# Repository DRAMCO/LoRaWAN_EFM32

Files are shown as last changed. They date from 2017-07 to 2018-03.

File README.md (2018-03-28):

# LoRaWAN_EFM32



LoRaMAC implementation based on the Semtech implemenation for the EFM32 Happy Gecko develop board.
Developed by [DRAMCO](http://www.dramco.be).

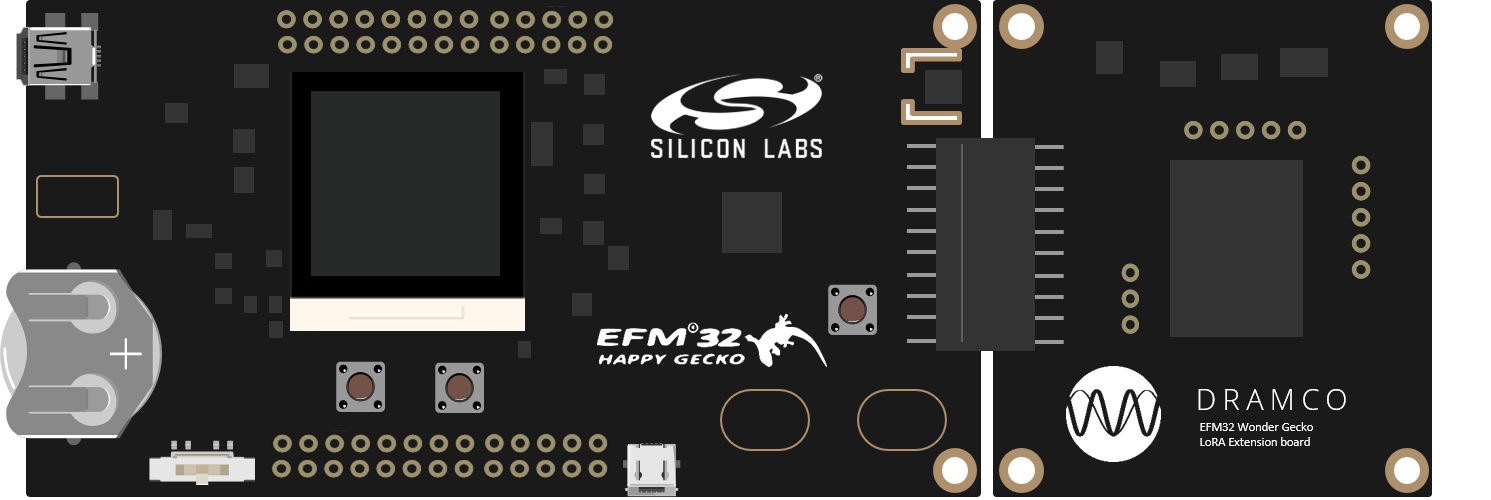
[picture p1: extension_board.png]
LoRaWAN EFM32 module


This project will be used in hands-on sessions to let attendees experience the development of low power IoT nodes.
The module was used in the following tutorials:
- [IEEE Sensors 2017](http://ieee-sensors2017.org/low-power-wireless-technologies-connecting-embedded-sensors-iot-journey-fundaments-hands)
- [IEEE PIMRC 2017](http://pimrc2017.ieee-pimrc.org/program/tutorials-2/)
- Workshop: [Connecting Embedded Sensors in the IoT](https://dramco.be/tutorials/connecting-embedded-sensors-in-the-iot)

The hands-on can be found [here](dramco.be/tutorials/low-power-iot) with the corresponding [presentation](https://www.slideshare.net/GillesCallebaut/low-power-wireless-technologies-for-connecting-embedded-sensors-in-the-iot-a-journey-from-fundaments-to-handson-90398582).

The DRAMCO LoRa module features a Semtech SX1272 Radio chip and an EFM32 Cortex M0 processor. 

## How to cite
```LaTex
@Misc{lorawan-efm32,
  author =   {G. Ottoy and G. Leenders and G. Callebaut},
  title =    {{LoRaWAN EFM32}},
  url = {https://github.com/DRAMCO/LoRaWAN_EFM32},
  note = {doi: \url{10.5281/zenodo.1209414}}
}
```

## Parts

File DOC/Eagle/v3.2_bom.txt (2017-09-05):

Partlist

Exported from v3.brd at 23/08/2017 9:41

EAGLE Version 8.2.2 Copyright (c) 1988-2017 Autodesk, Inc.

Assembly variant: 

Part     Value                 Package                  Library  Supplier   Ordernr          Price/piece

C1       10n                   C0805K                   rcl      
C2       100n                  C0805K                   rcl      
C3       100n                  C0805K                   rcl      
C4       100n                  C0805K                   rcl      
C5       1u                    C0805K                   rcl      
IC1      APDS-9200             APDS-9200                project  Mouser     630-APDS-9200    1.37
IC2      PIC12LF1552           MSOP8                    project  RS         799-0281	     0.559 (per 10)
IC3      M24C01/02-XTSSOP08    TSSOP08                  project  RS         714-7575	     0.141 (per 25)
JP1      SMH-110-X2-XX-D       SMH-110-X2-XX-D          project  Farnell    2019809          4.03
JP2                            1X03                     pinhead
JP3                            1X06                     pinhead
JP4                            1X04                     pinhead  
JP5                            1X05                     pinhead  
JP6      PICKIT-HEADERSMD-PADS 1X06/SMD                 project  
LED1                           CHIP-LED0805             led      RS         654-5773	     0.052 (per 50)
M1       RF-LORA-868-SO        RF-LORA-868-SO           project  RS         903-3059	    13.50
R1       4k7                   M0805                    rcl      
R2       4k7                   M0805                    rcl      
R3       4k7                   M0805                    rcl      
R4       1k2                   M0805                    rcl      
R5       6k8                   M0805                    rcl      
X1       SMA-142-0701-871/876  J502-ND-142-0701-871/876 con-coax Farnell    2340523          4.77  (min. 10)
A1	 Antenna 868 MHz       /                        /        RS         542-563          5.19

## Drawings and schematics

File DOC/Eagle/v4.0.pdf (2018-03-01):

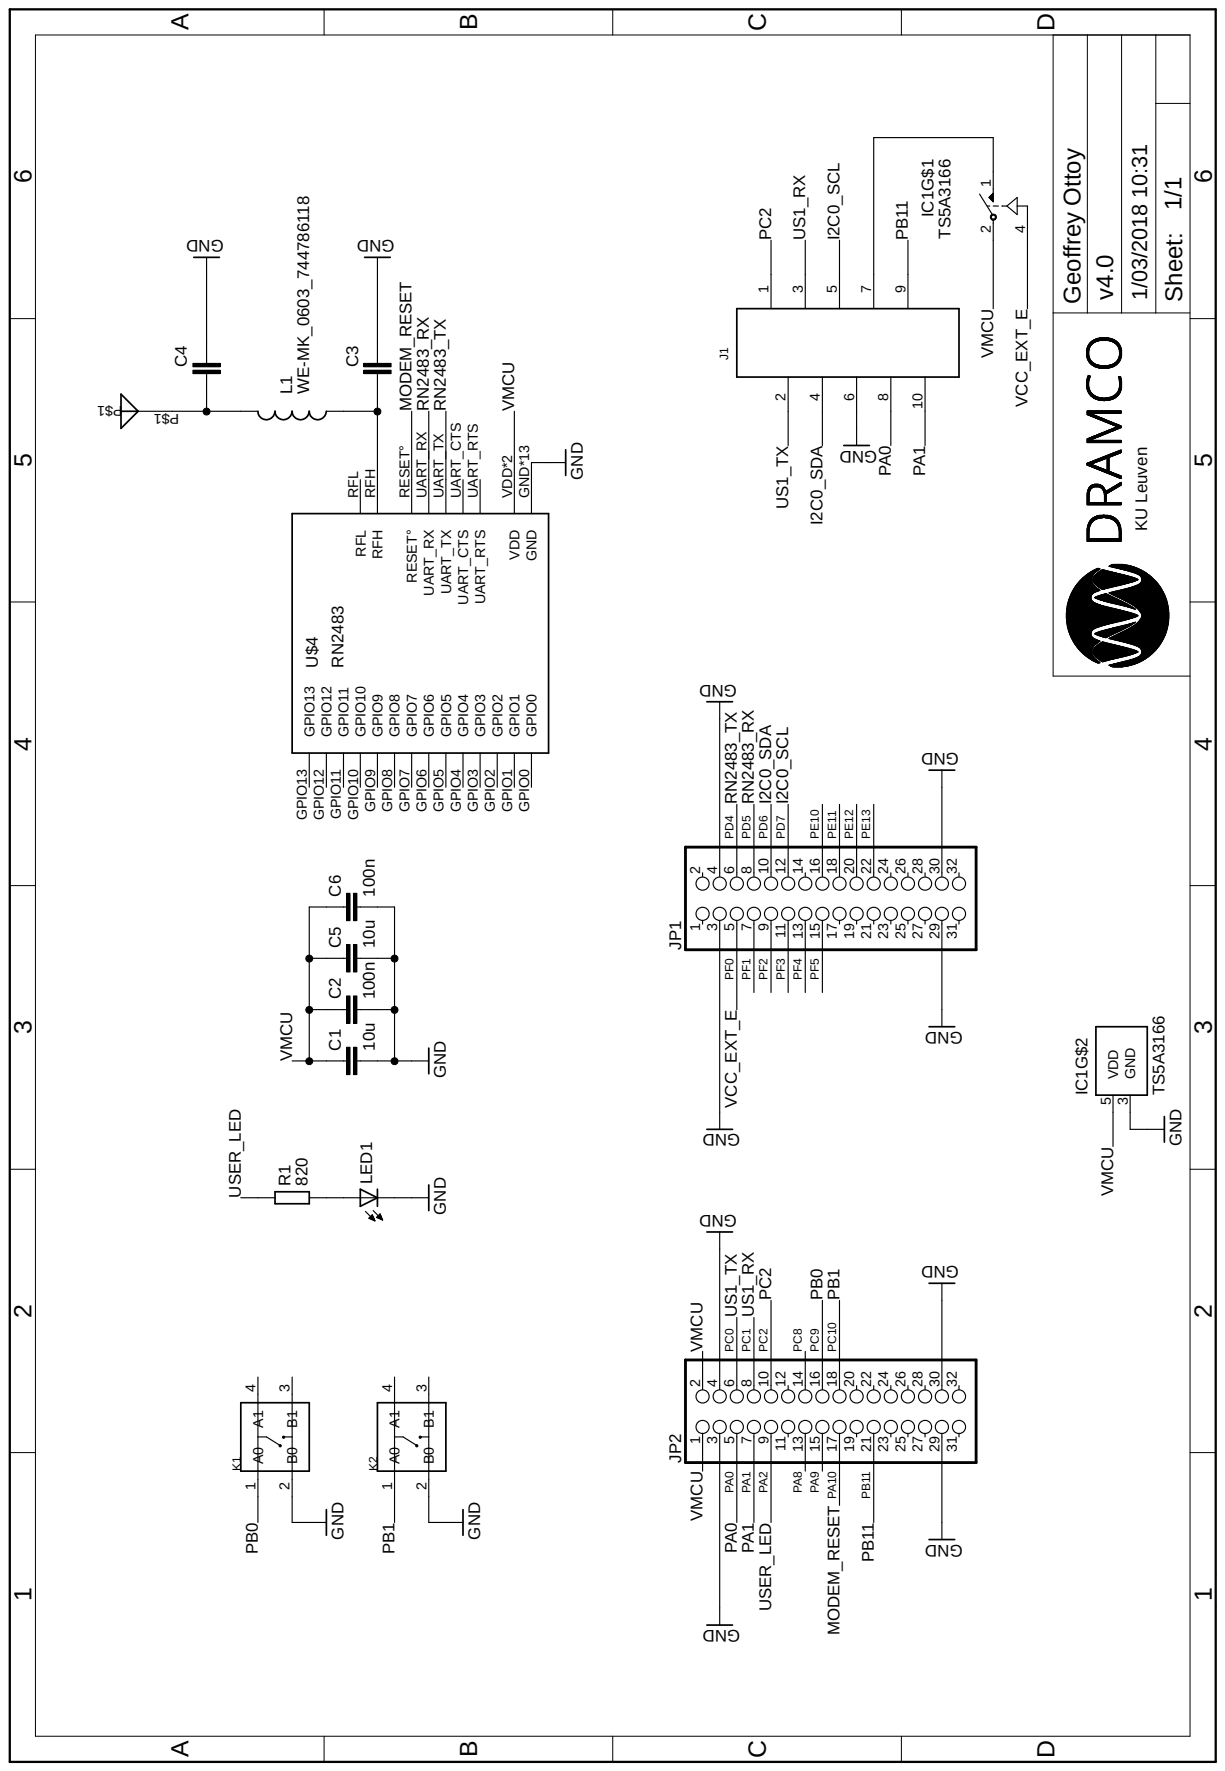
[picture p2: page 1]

P$1 P$1 L1 C5 C6 IC1G$1 4 1 2 IC1G$2 GND 3 VDD 5 VMCU VMCU VMCU VMCU VMCU VMCU PC0 PC1 PC2 PC2 PC8 PC9 PC10 PA0 PA0 PA1 PA1 PA2 PA8 PA9 PA10 PB11 PB11 PD4 PD5 PD6 PD7 PE10 PE11 PE12 PE13 PF0 PF1 PF2 PF3 PF4 PF5 v4.0 1/03/2018 10:31 1/1 Sheet: ABCD 1 2 3 4 5 6 ABCD 1 2 3 4 5 6

Geoffrey Ottoy KU Leuven 10u 100n GND RN2483 GND

GND GND WE-MK_0603_744786118 10u 100n TS5A3166 TS5A3166 GND I2C0_SDA I2C0_SCL PC2 PB0 PB1 PA0 PA1 PB11 MODEM_RESET RN2483_RX RN2483_TX RN2483_TX RN2483_RX MODEM_RESET I2C0_SCL I2C0_SDA US1_TX US1_RX US1_TX US1_RX PB0 PB1 USER_LED USER_LED VCC_EXT_E VCC_EXT_E C1 C2 GND GND*13 UART_TX UART_TX UART_RX UART_RX VDD VDD*2 RFH RFH RFL RFL RESET° RESET° U$4 UART_CTS UART_CTS UART_RTS UART_RTS GPIO0 GPIO0 GPIO1 GPIO1 GPIO2 GPIO2 GPIO3 GPIO3 GPIO4 GPIO4 GPIO5 GPIO5 GPIO6 GPIO6 GPIO7 GPIO7 GPIO8 GPIO8 GPIO9 GPIO9 GPIO10 GPIO10 GPIO11 GPIO11 GPIO12 GPIO12 GPIO13 GPIO13 JP21 2 3 4 5 6 7 8 9 10 11 12 13 14 15 16 17 18 19 20 21 22 23 24 25 26 27 28 29 30 31 32 JP11 2 3 4 5 6 7 8 9 10 11 12 13 14 15 16 17 18 19 20 21 22 23 24 25 26 27 28 29 30 31 32 J1 10 9 8 7 6 5 4 3 2 1 K1A0 1 A1 4 B0 2 B1 3 K2A0 1 A1 4 B0 2 B1 3 R1LED1 C4 C3

GND GND GND 820 GND

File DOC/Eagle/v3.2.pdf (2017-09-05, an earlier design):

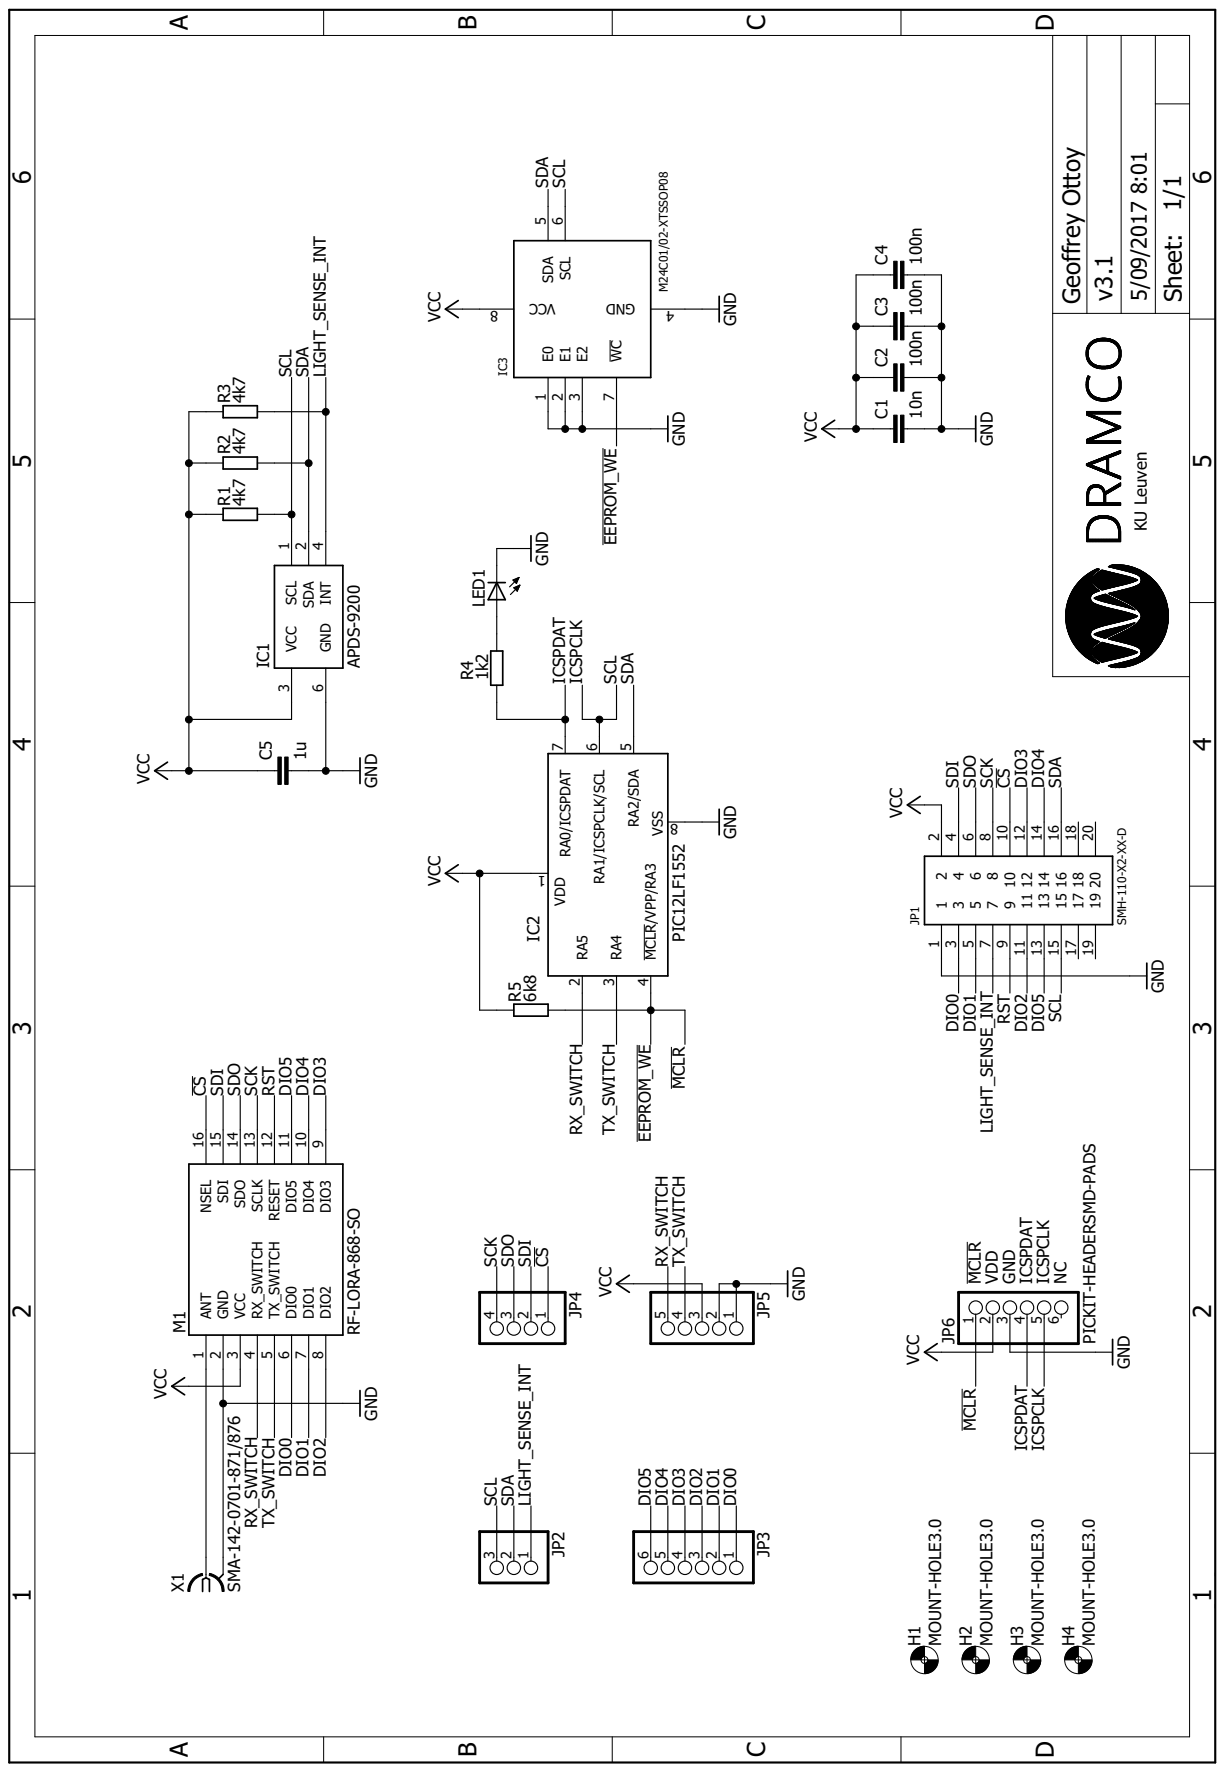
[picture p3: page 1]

Geof rey Ottoy KU Leuven MCLR VDD GND ICSPDAT ICSPCLK NC SMH-110-X2-XX-D GND VCC RF-LORA-868-SO VCC SMA-142-0701-871/876GND 10n 100n VCC GND 4k7 4k7 4k7 1u GND VCC VCC GND APDS-9200 MOUNT-HOLE3.0 MOUNT-HOLE3.0 MOUNT-HOLE3.0 MOUNT-HOLE3.0 PICKIT-HEADERSMD-PADS PIC12LF1552 GND 100n VCC GND VCC 100n M24C01/02-XTSSOP08 VCC GND GND 1k2 GND 6k8 ICSPCLK ICSPCLK EEPROM_WE EEPROM_WE JP11 1 2 2 3 3 4 4 5 5 6 6 7 7 8 8 9 9 10 10 11 11 12 12 13 13 14 14 15 15 16 16 17 17 18 18 19 19 20 20 ANT 1 GND 2 VCC 3 RX_SWITCH 4 TX_SWITCH 5 DIO0 6 DIO1 7 DIO2 8 DIO3 9 DIO4 10 DIO5 11 RESET 12 SCLK 13 SDO 14 SDI 15 NSEL 16 M1 X1 C1 C2 R1 R2 R3 C5 JP2 321JP3 654321 JP4 4321JP5 54321 VCC 3 GND 6 SCL 1 SDA 2 INT 4 IC1 H1H2H4H3 JP6123456 VDD VSS IC2 1 8 RA5 2 RA0/ICSPDAT 7 RA4 3 RA2/SDA 5 RA1/ICSPCLK/SCL 6 MCLR/VPP/RA3 4 C3 C4 E0 1 E1 2 E2 3 DNG 4 SDA 5 SCL 6 WC 7 CCV 8IC3 LED1 R4 R5 RX_SWITCH RX_SWITCH RX_SWITCH TX_SWITCH TX_SWITCH TX_SWITCH DIO0 DIO0 DIOD0IO1 DIO1 DIO1 DIO2 DIO2 DIO2 SCK SCK SCK SDO SDO SDO SDI SDI SDI CS CS CS RST RST DIO5 DIO5 DIO5 DIO4 DIO4 DIO4 DIO3 DIO3 DIO3 SCL SCL SCL SCL SCL SDA SDA SDA SDA SDA LIGHT_SENSE_INT LIGHT_SENSE_INT LIGHT_SENSE_INT ICSPDAT ICSPDAT MCLR MCLR v3.1 5/09/2017 8:01 1/1 Sheet: ABCD 1 2 3 4 5 6 ABCD 1 2 3 4 5 6

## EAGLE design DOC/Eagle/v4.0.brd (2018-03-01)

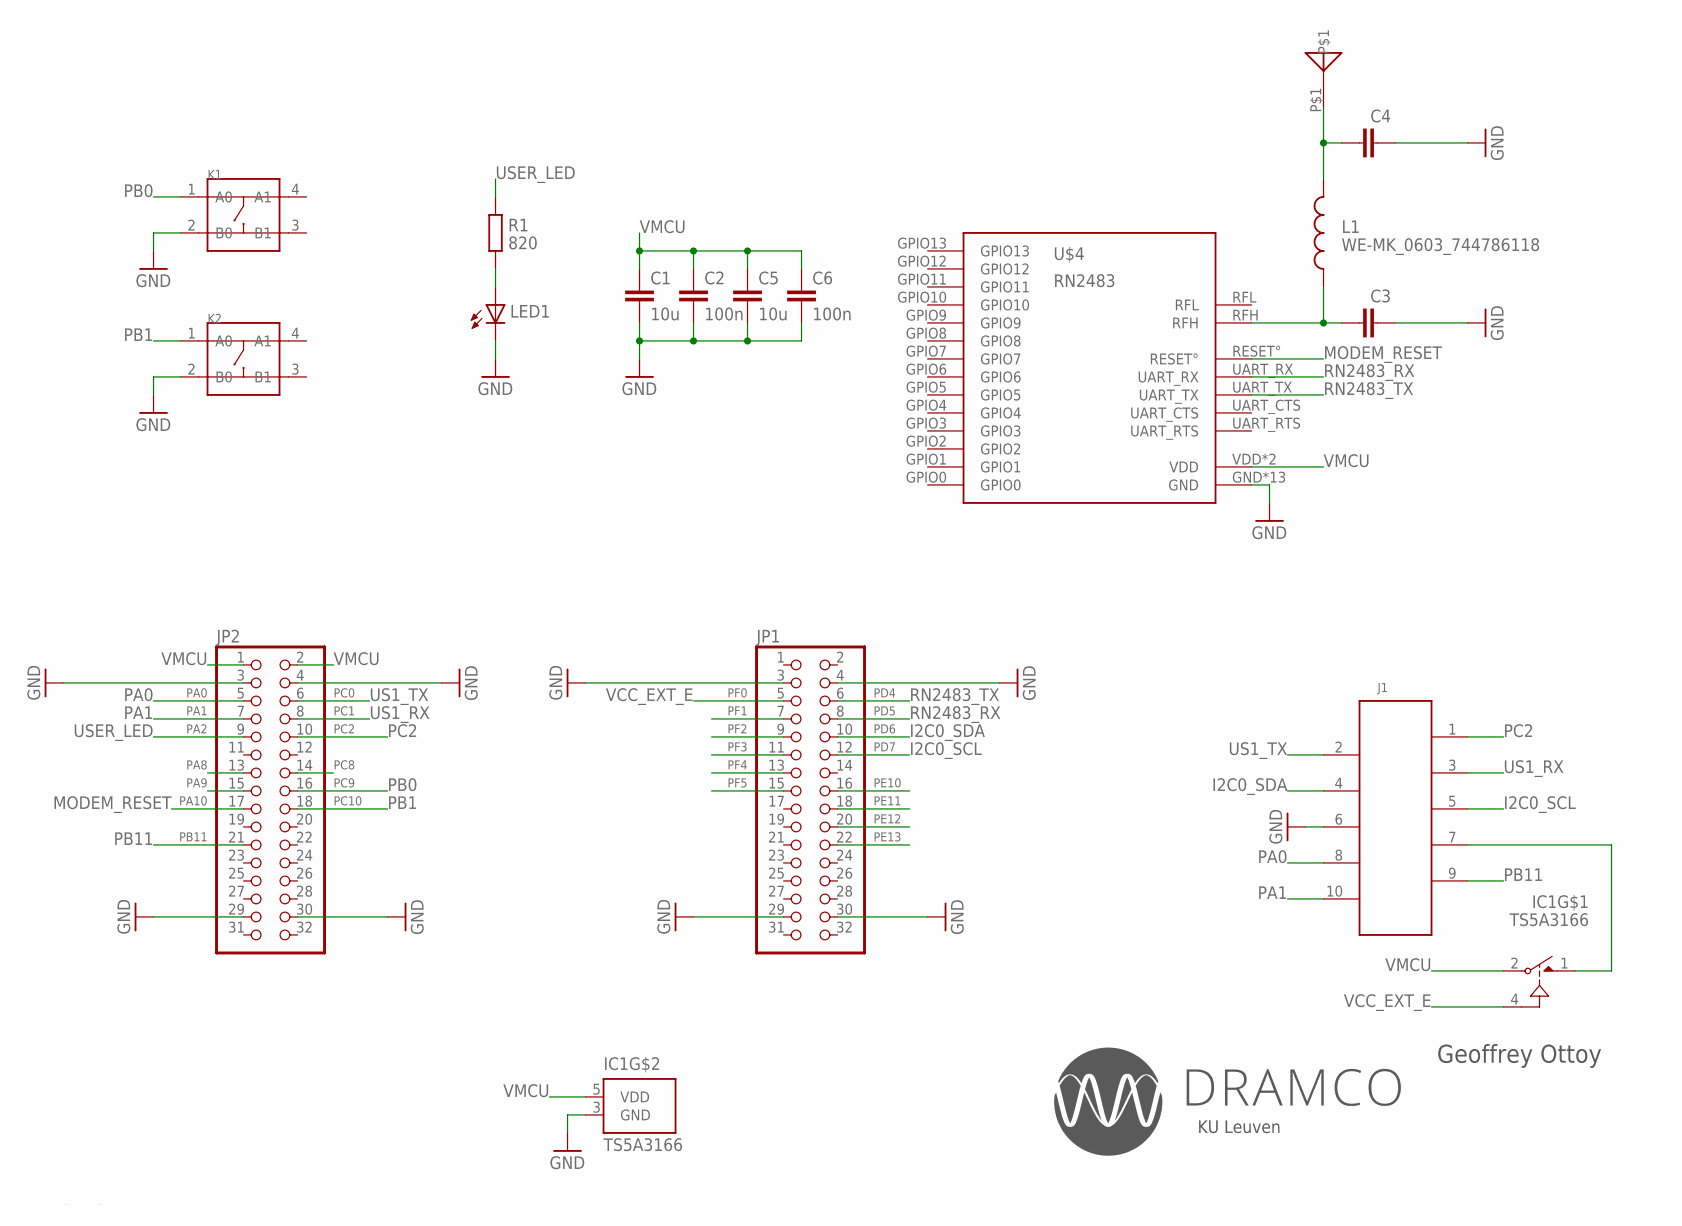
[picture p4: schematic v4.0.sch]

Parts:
C1, C5: 10u; C0805K
C2, C6: 100n; C0805K
C3, C4: C-EUC0603K; C0603K
IC1: TS5A3166; SC70-5L
J1: 61001018321
JP1, JP2: PINHD-2X16; 2X16
K1, K2: SMD-SWITCH-TACTILE-SPST-NO(4P-D6.0MM); SW4-SMD-6.0X6.0X5.0MM
L1: WE-MK_0603_744786118; WE-MK_0603
LED1: LEDCHIPLED_0805; CHIPLED_0805
R1: 820; R0805
U$2: ANTENNA868; CERAMIC-ANTENNA
U$4: RN2483

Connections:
GND: C1.2, C2.2, C3.1, C4.1, C5.2, C6.2, IC1.3 (GND), J1.6 (5), JP1.3, JP1.4, JP1.29, JP1.30, JP2.3, JP2.4, JP2.29, JP2.30, K1.2 (B0), K2.2 (B0), LED1.C, U$4.GND, U$4.GND1 (GND), U$4.GND2 (GND), U$4.GND3 (GND), U$4.GND4 (GND), U$4.GND5 (GND), U$4.GND6 (GND), U$4.GND7 (GND), U$4.GND8 (GND), U$4.GND9 (GND), U$4.GND10 (GND), U$4.GND11 (GND), U$4.GND12 (GND)
unnamed: LED1.A, R1.1
unnamed: C3.2, L1.1, U$4.RFH
unnamed: C4.2, L1.2, U$2.P$1
unnamed: IC1.1 (NO), J1.7 (4)
PA0: J1.8 (3), JP2.5
PA1: J1.10 (1), JP2.7
PA2: JP2.9, R1.2
PA8: JP2.13
PA9: JP2.15
PA10: JP2.17, U$4.RESET°
PB11: J1.9 (2), JP2.21
PC0: J1.2 (9), JP2.6
PC1: J1.3 (8), JP2.8
PC2: J1.1 (10), JP2.10
PC8: JP2.14
PC9: JP2.16, K1.1 (A0)
PC10: JP2.18, K2.1 (A0)
PD4: JP1.6, U$4.UART_TX
PD5: JP1.8, U$4.UART_RX
PD6: J1.4 (7), JP1.10
PD7: J1.5 (6), JP1.12
PE10: JP1.16
PE11: JP1.18
PE12: JP1.20
PE13: JP1.22
PF0: IC1.4 (IN), JP1.5
PF1: JP1.7
PF2: JP1.9
PF3: JP1.11
PF4: JP1.13
PF5: JP1.15
VMCU: C1.1, C2.1, C5.1, C6.1, IC1.2 (COM), IC1.5 (VDD), JP2.1, JP2.2, U$4.VDD, U$4.VDD2 (VDD)

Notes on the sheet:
Geoffrey Ottoy
KU Leuven
I2C0_SDA
I2C0_SCL
PC2
PB0
PB1
PA0
PA1
PB11
MODEM_RESET
RN2483_RX
RN2483_TX
US1_TX
US1_RX
USER_LED
VCC_EXT_E

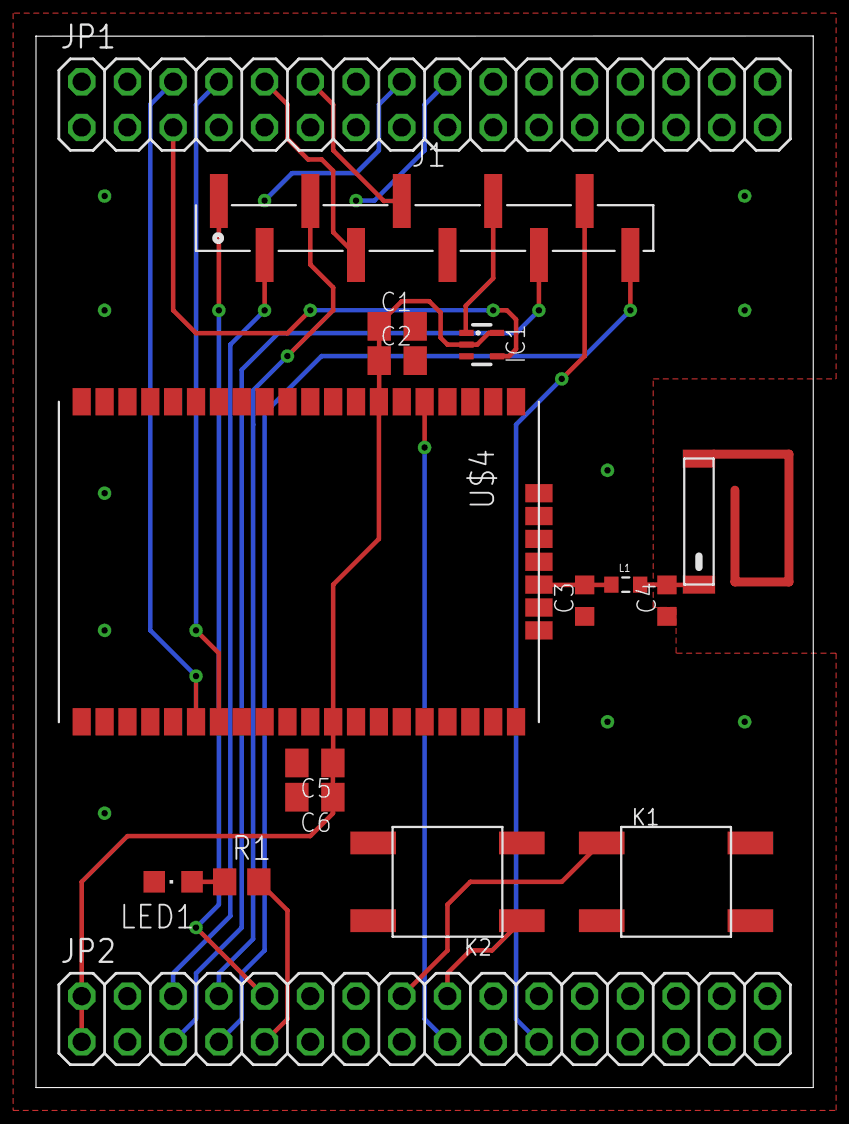
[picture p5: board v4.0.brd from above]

Board: 2 copper layers, 43.2 x 58.4 mm, 17 parts (0 on the bottom side), 21 nets.

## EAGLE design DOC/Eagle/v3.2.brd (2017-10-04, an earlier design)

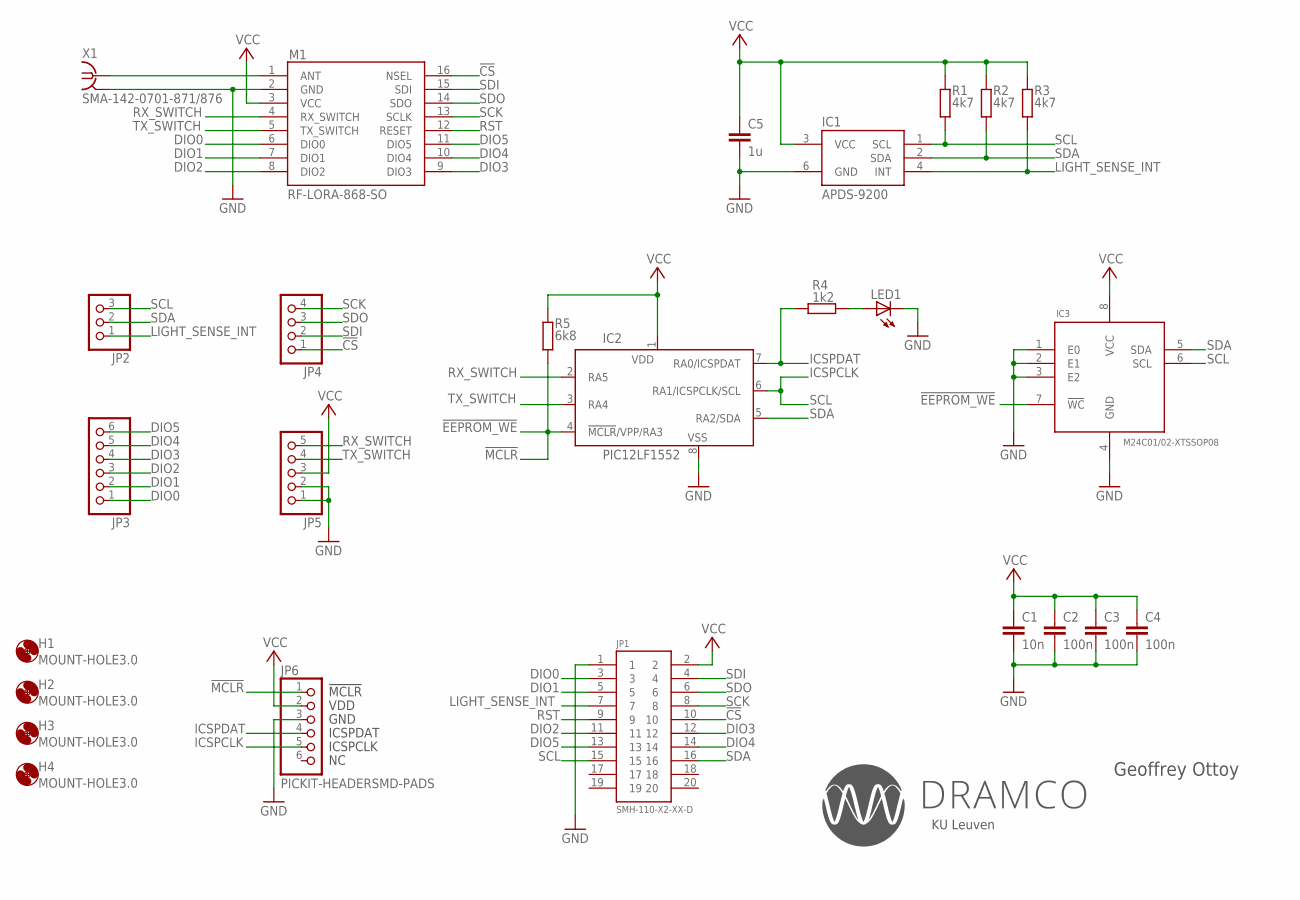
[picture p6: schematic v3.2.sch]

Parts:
C1: 10n; C0805K
C2, C3, C4: 100n; C0805K
C5: 1u; C0805K
H1, H2, H3, H4: MOUNT-HOLE3.0; 3,0
IC1: APDS-9200
IC2: PIC12LF1552; MSOP8
IC3: M24C01/02-XTSSOP08; TSSOP08
JP1: SMH-110-X2-XX-D
JP2: PINHD-1X3; 1X03
JP3: PINHD-1X6; 1X06
JP4: PINHD-1X4; 1X04
JP5: PINHD-1X5; 1X05
JP6: PICKIT-HEADERSMD-PADS; 1X06/SMD
LED1: LEDCHIP-LED0805; CHIP-LED0805
M1: RF-LORA-868-SO
R1, R2, R3: 4k7; M0805
R4: 1k2; M0805
R5: 6k8; M0805
X1: SMA-142-0701-871/876; J502-ND-142-0701-871/876

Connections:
!CS: JP1.10, JP4.1, M1.16 (NSEL)
!MCLR: IC2.4 (!MCLR!/VPP/RA3), IC3.7 (!WC), JP6.1, R5.1
ANT: M1.1 (ANT), X1.1
DIO0: JP1.3, JP3.1, M1.6 (DIO0)
DIO1: JP1.5, JP3.2, M1.7 (DIO1)
DIO2: JP1.11, JP3.3, M1.8 (DIO2)
DIO3: JP1.12, JP3.4, M1.9 (DIO3)
DIO4: JP1.14, JP3.5, M1.10 (DIO4)
DIO5: JP1.13, JP3.6, M1.11 (DIO5)
GND: C1.2, C2.2, C3.2, C4.2, C5.2, IC1.6 (GND), IC2.8 (VSS), IC3.1 (E0), IC3.2 (E1), IC3.3 (E2), IC3.4 (GND), JP1.1, JP5.1, JP5.2, JP6.3, LED1.C, M1.2 (GND), X1.G@1 (2), X1.G@2 (2), X1.G@3 (2), X1.G@4 (2)
ICSPDAT: IC2.7 (RA0/ICSPDAT), JP6.4, R4.2
LIGHT_SENSE_INT: IC1.4 (INT), JP1.7, JP2.1, R3.1
unnamed: LED1.A, R4.1
RST: JP1.9, M1.12 (RESET)
RX_SWITCH: IC2.2 (RA5), JP5.5, M1.4 (RX_SWITCH)
SCK: JP1.8, JP4.4, M1.13 (SCLK)
SCL: IC1.1 (SCL), IC2.6 (RA1/ICSPCLK/SCL), IC3.6 (SCL), JP1.15, JP2.3, JP6.5, R1.1
SDA: IC1.2 (SDA), IC2.5 (RA2/SDA), IC3.5 (SDA), JP1.16, JP2.2, R2.1
SDI: JP1.4, JP4.2, M1.15 (SDI)
SDO: JP1.6, JP4.3, M1.14 (SDO)
TX_SWITCH: IC2.3 (RA4), JP5.4, M1.5 (TX_SWITCH)
VCC: C1.1, C2.1, C3.1, C4.1, C5.1, IC1.3 (VCC), IC2.1 (VDD), IC3.8 (VCC), JP1.2, JP5.3, JP6.2, M1.3 (VCC), R1.2, R2.2, R3.2, R5.2

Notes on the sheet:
Geoffrey Ottoy
KU Leuven
ICSPCLK
!EEPROM_WE

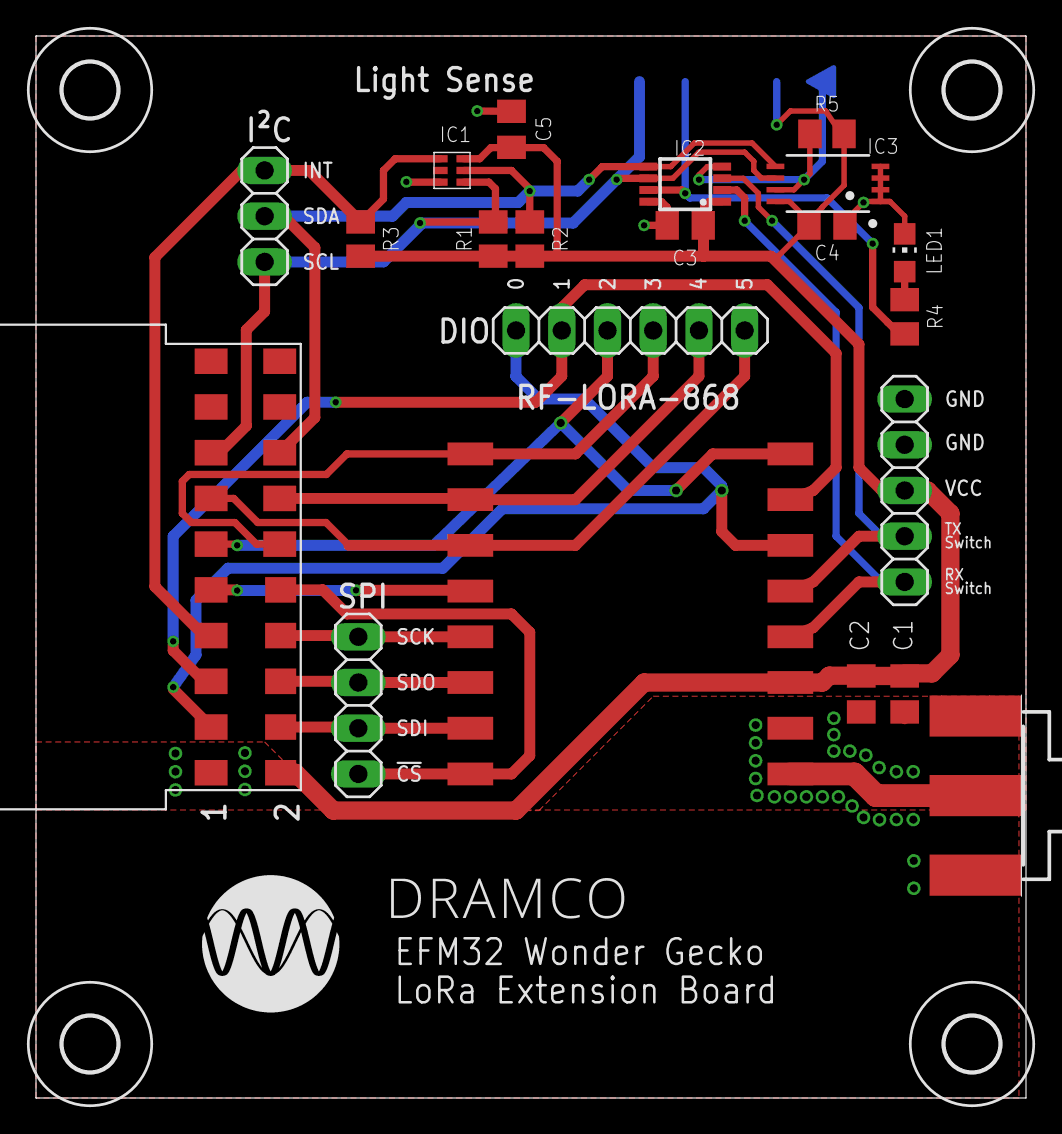
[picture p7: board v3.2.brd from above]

Board: 2 copper layers, 55.0 x 59.0 mm, 26 parts (1 on the bottom side), 22 nets.

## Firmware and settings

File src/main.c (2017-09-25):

/*  ____  ____      _    __  __  ____ ___
 * |  _ \|  _ \    / \  |  \/  |/ ___/ _ \
 * | | | | |_) |  / _ \ | |\/| | |  | | | |
 * | |_| |  _ <  / ___ \| |  | | |__| |_| |
 * |____/|_| \_\/_/   \_\_|  |_|\____\___/
 *                           research group
 *                             dramco.be/
 *
 *   KU Leuven - Technology Campus Gent,
 *   Gebroeders De Smetstraat 1,
 *   B-9000 Gent, Belgium
 *
 *         File: main.c
 *      Created: 2017-09-20
 *       Author: Geoffrey Ottoy
 *
 *  Description: Main function running on the EFM32.
 *  	The type of application can be selected (see app_select.h)
 */


#include "app_select.h"
#if defined(APP_TYPE) && (APP_TYPE == EXAMPLE_APP)
#include "example_app.h"
#endif
#if defined(APP_TYPE) && (APP_TYPE == AES_APP)
#include "aes_app.h"
#endif
#if defined(APP_TYPE) && (APP_TYPE == DEEP_SLEEP_APP)
#include "deep_sleep_app.h"
#endif

int main(void){
#if defined(APP_TYPE) && (APP_TYPE == AES_APP)
	main_aes();
#endif

#if defined(APP_TYPE) && (APP_TYPE == EXAMPLE_APP)
	main_example();
#endif

#if defined(APP_TYPE) && (APP_TYPE == DEEP_SLEEP_APP)
	main_deep_sleep();
#endif
	while(1);
}

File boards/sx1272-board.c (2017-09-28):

/*
 / _____)             _              | |
( (____  _____ ____ _| |_ _____  ____| |__
 \____ \| ___ |    (_   _) ___ |/ ___)  _ \
 _____) ) ____| | | || |_| ____( (___| | | |
(______/|_____)_|_|_| \__)_____)\____)_| |_|
    (C)2013 Semtech

Description: SX1272 driver specific target board functions implementation

License: Revised BSD License, see LICENSE.TXT file include in the project

Maintainer: Miguel Luis and Gregory Cristian
*/
#include "board.h"
#include "radio.h"
#include "sx1272.h"
#include "sx1272-board.h"
#ifdef HW_VERSION_3
#include "omux-board.h"
#endif

/*!
 * Flag used to set the RF switch control pins in low power mode when the radio is not active.
 */
static bool RadioIsActive = false;

/*!
 * Radio driver structure initialization
 */
const struct Radio_s Radio =
{
    SX1272Init,
    SX1272GetStatus,
    SX1272SetModem,
    SX1272SetChannel,
    SX1272IsChannelFree,
    SX1272Random,
    SX1272SetRxConfig,
    SX1272SetTxConfig,
    SX1272CheckRfFrequency,
    SX1272GetTimeOnAir,
    SX1272Send,
    SX1272SetSleep,
    SX1272SetStby,
    SX1272SetRx,
    SX1272StartCad,
    SX1272SetTxContinuousWave,
    SX1272ReadRssi,
    SX1272Write,
    SX1272Read,
    SX1272WriteBuffer,
    SX1272ReadBuffer,
    SX1272SetMaxPayloadLength,
    SX1272SetPublicNetwork
};

/*!
 * Antenna switch GPIO pins objects
 */
Gpio_t AntRx;
Gpio_t AntTx;

void SX1272IoInit( void )
{
    GpioInit( &SX1272.Spi.Nss, RADIO_NSS, PIN_OUTPUT, PIN_PUSH_PULL, PIN_PULL_UP, 1 );

    GpioInit( &SX1272.DIO0, RADIO_DIO_0, PIN_INPUT, PIN_PUSH_PULL, PIN_PULL_UP, 0 );
    GpioInit( &SX1272.DIO1, RADIO_DIO_1, PIN_INPUT, PIN_PUSH_PULL, PIN_PULL_UP, 0 );
    GpioInit( &SX1272.DIO2, RADIO_DIO_2, PIN_INPUT, PIN_PUSH_PULL, PIN_PULL_UP, 0 );
    GpioInit( &SX1272.DIO3, RADIO_DIO_3, PIN_INPUT, PIN_PUSH_PULL, PIN_PULL_UP, 0 );
    GpioInit( &SX1272.DIO4, RADIO_DIO_4, PIN_INPUT, PIN_PUSH_PULL, PIN_PULL_UP, 0 );
    GpioInit( &SX1272.DIO5, RADIO_DIO_5, PIN_INPUT, PIN_PUSH_PULL, PIN_PULL_UP, 0 );
}

void SX1272IoIrqInit( DioIrqHandler **irqHandlers )
{
    GpioSetInterrupt( &SX1272.DIO0, IRQ_RISING_EDGE, IRQ_HIGH_PRIORITY, irqHandlers[0] );
    GpioSetInterrupt( &SX1272.DIO1, IRQ_RISING_EDGE, IRQ_HIGH_PRIORITY, irqHandlers[1] );
    GpioSetInterrupt( &SX1272.DIO2, IRQ_RISING_EDGE, IRQ_HIGH_PRIORITY, irqHandlers[2] );
    GpioSetInterrupt( &SX1272.DIO3, IRQ_RISING_EDGE, IRQ_HIGH_PRIORITY, irqHandlers[3] );
    GpioSetInterrupt( &SX1272.DIO4, IRQ_RISING_EDGE, IRQ_HIGH_PRIORITY, irqHandlers[4] );
    //GpioSetInterrupt( &SX1272.DIO5, IRQ_RISING_EDGE, IRQ_HIGH_PRIORITY, irqHandlers[5] );
}

void SX1272IoDeInit( void )
{
    GpioInit( &SX1272.Spi.Nss, RADIO_NSS, PIN_OUTPUT, PIN_PUSH_PULL, PIN_PULL_UP, 1 );

    GpioInit( &SX1272.DIO0, RADIO_DIO_0, PIN_INPUT, PIN_PUSH_PULL, PIN_NO_PULL, 0 );
    GpioInit( &SX1272.DIO1, RADIO_DIO_1, PIN_INPUT, PIN_PUSH_PULL, PIN_NO_PULL, 0 );
    GpioInit( &SX1272.DIO2, RADIO_DIO_2, PIN_INPUT, PIN_PUSH_PULL, PIN_NO_PULL, 0 );
    GpioInit( &SX1272.DIO3, RADIO_DIO_3, PIN_INPUT, PIN_PUSH_PULL, PIN_NO_PULL, 0 );
    GpioInit( &SX1272.DIO4, RADIO_DIO_4, PIN_INPUT, PIN_PUSH_PULL, PIN_NO_PULL, 0 );
    GpioInit( &SX1272.DIO5, RADIO_DIO_5, PIN_INPUT, PIN_PUSH_PULL, PIN_NO_PULL, 0 );
}

void SX1272SetRfTxPower( int8_t power )
{
    uint8_t paConfig = 0;
    uint8_t paDac = 0;

    paConfig = SX1272Read( REG_PACONFIG );
    paDac = SX1272Read( REG_PADAC );

    paConfig = ( paConfig & RF_PACONFIG_PASELECT_MASK ) | SX1272GetPaSelect( SX1272.Settings.Channel );

    if( ( paConfig & RF_PACONFIG_PASELECT_PABOOST ) == RF_PACONFIG_PASELECT_PABOOST )
    {
        if( power > 17 )
        {
            paDac = ( paDac & RF_PADAC_20DBM_MASK ) | RF_PADAC_20DBM_ON;
        }
        else
        {
            paDac = ( paDac & RF_PADAC_20DBM_MASK ) | RF_PADAC_20DBM_OFF;
        }
        if( ( paDac & RF_PADAC_20DBM_ON ) == RF_PADAC_20DBM_ON )
        {
            if( power < 5 )
            {
                power = 5;
            }
            if( power > 20 )
            {
                power = 20;
            }
            paConfig = ( paConfig & RFLR_PACONFIG_OUTPUTPOWER_MASK ) | ( uint8_t )( ( uint16_t )( power - 5 ) & 0x0F );
        }
        else
        {
            if( power < 2 )
            {
                power = 2;
            }
            if( power > 17 )
            {
                power = 17;
            }
            paConfig = ( paConfig & RFLR_PACONFIG_OUTPUTPOWER_MASK ) | ( uint8_t )( ( uint16_t )( power - 2 ) & 0x0F );
        }
    }
    else
    {
        if( power < -1 )
        {
            power = -1;
        }
        if( power > 14 )
        {
            power = 14;
        }
        paConfig = ( paConfig & RFLR_PACONFIG_OUTPUTPOWER_MASK ) | ( uint8_t )( ( uint16_t )( power + 1 ) & 0x0F );
    }
    SX1272Write( REG_PACONFIG, paConfig );
    SX1272Write( REG_PADAC, paDac );
}

uint8_t SX1272GetPaSelect( uint32_t channel )
{
    return RF_PACONFIG_PASELECT_PABOOST;
}
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

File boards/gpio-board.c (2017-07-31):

/*
 / _____)             _              | |
( (____  _____ ____ _| |_ _____  ____| |__
 \____ \| ___ |    (_   _) ___ |/ ___)  _ \
 _____) ) ____| | | || |_| ____( (___| | | |
(______/|_____)_|_|_| \__)_____)\____)_| |_|
    (C)2013 Semtech

Description: Bleeper board GPIO driver implementation

License: Revised BSD License, see LICENSE.TXT file include in the project

Maintainer: Miguel Luis and Gregory Cristian
*/
#include "board.h"
#include "gpio-board.h"
#include "em_gpio.h"
#include "em_cmu.h"

#define PIN_DIO_0		0
#define PIN_DIO_1   	7
#define PIN_DIO_2   	1
#define PIN_DIO_3   	6
#define PIN_DIO_4   	5

#define PIN_BUTTON_0   	9
#define PIN_BUTTON_1   	10

#define PIN_LIGHT_SENSE	2 // Future use

static GpioIrqHandler *GpioIrq[16];

void GpioMcuInit( Gpio_t *obj, PinNames pin, PinModes mode, PinConfigs config, PinTypes type, uint32_t value )
{
    if( pin == NC )
    {
        return;
    }
    obj->pin = pin;
    obj->pinIndex = (0x01 << (obj->pin & 0x0F));
    obj->portIndex = ((obj->pin >> 4) & 0x0F);

    // We don't use the port variable on this board
    obj->port = NULL;

    if (mode == PIN_INPUT)
        GPIO_PinModeSet(obj->portIndex, obj->pin & 0x0F, gpioModeInput, value);
    else
        GPIO_PinModeSet(obj->portIndex, obj->pin & 0x0F, gpioModePushPull, value);

    // Sets initial output value
    if( mode == PIN_OUTPUT )
        GpioMcuWrite( obj, value );
}

void GpioMcuSetInterrupt( Gpio_t *obj, IrqModes irqMode, IrqPriorities irqPriority, GpioIrqHandler *irqHandler )
{
	if (irqHandler == NULL)
		return;

	bool risingEdge = false;
	bool fallingEdge = false;
	switch( irqMode )
	{
		case NO_IRQ:
			break;
		case IRQ_RISING_EDGE:
			risingEdge = true;
			break;
		case IRQ_FALLING_EDGE:
			fallingEdge = true;
			break;
		case IRQ_RISING_FALLING_EDGE:
			risingEdge = true;
			fallingEdge = true;
			break;
	}

	uint32_t priority = 0;
	switch( irqPriority )
	{
	case IRQ_VERY_LOW_PRIORITY:
	case IRQ_LOW_PRIORITY:
		priority = 3;
		break;
	case IRQ_MEDIUM_PRIORITY:
		priority = 2;
		break;
	case IRQ_HIGH_PRIORITY:
		priority = 1;
		break;
	case IRQ_VERY_HIGH_PRIORITY:
	default:
		priority = 0;
		break;
	}

	GPIO_IntConfig(obj->portIndex, obj->pin & 0x0F, risingEdge, fallingEdge, true);

	NVIC_SetPriority(GPIO_ODD_IRQn , priority);
	NVIC_SetPriority(GPIO_EVEN_IRQn , priority);

	NVIC_EnableIRQ(GPIO_ODD_IRQn);
	NVIC_EnableIRQ(GPIO_EVEN_IRQn);

	GpioIrq[(obj->pin) & 0x0F] = irqHandler;
}

void GpioMcuRemoveInterrupt( Gpio_t *obj )
{
	assert_param( FAIL );
	/*
    GPIO_InitTypeDef   GPIO_InitStructure;

    GPIO_InitStructure.Pin =  obj->pinIndex ;
    GPIO_InitStructure.Mode = GPIO_MODE_ANALOG;
    HAL_GPIO_Init( obj->port, &GPIO_InitStructure );*/
}

void GpioMcuWrite( Gpio_t *obj, uint32_t value )
{
	if( obj == NULL )
	{
		assert_param( FAIL );
	}
    // Check if pin is not connected
    if( obj->pin == NC )
    {
        return;
    }

    if (value)
    	GPIO_PinOutSet(obj->portIndex, obj->pin & 0x0F);
    else
    	GPIO_PinOutClear(obj->portIndex, obj->pin & 0x0F);
}

void GpioMcuToggle( Gpio_t *obj )
{
	assert_param(obj != NULL);
    if( obj == NULL )
    {
        assert_param( FAIL );
    }

    // Check if pin is not connected
    if( obj->pin == NC )
    {
        return;
    }

    GPIO_PinOutToggle(obj->portIndex, obj->pin & 0x0F);
}

uint32_t GpioMcuRead( Gpio_t *obj )
{
    if( obj == NULL )
    {
        assert_param( FAIL );
    }
    // Check if pin is not connected
    if( obj->pin == NC )
    {
        return 0;
    }

    return GPIO_PinOutGet(obj->portIndex, obj->pin & 0x0F);
}

void GPIO_ODD_IRQHandler(void)
{
	uint32_t i = GPIO_IntGet();
	GPIO_IntClear(0xAAAA);

	if (i & (1 << PIN_DIO_1))
	{
		if (GpioIrq[PIN_DIO_1] != NULL)
			GpioIrq[PIN_DIO_1]();
	}

	if (i & (1 << PIN_DIO_2))
	{
		if (GpioIrq[PIN_DIO_2] != NULL)
			GpioIrq[PIN_DIO_2]();
	}

	if (i & (1 << PIN_DIO_4))
	{
		if (GpioIrq[PIN_DIO_4] != NULL)
			GpioIrq[PIN_DIO_4]();
	}

	if (i & (1 << PIN_BUTTON_0))
	{
		if (GpioIrq[PIN_BUTTON_0] != NULL)
			GpioIrq[PIN_BUTTON_0]();
	}
 }

void GPIO_EVEN_IRQHandler(void)
 {
	uint32_t i = GPIO_IntGet();
	GPIO_IntClear(0x5555);

	if (i & (1 << PIN_DIO_0))
	{
		if (GpioIrq[PIN_DIO_0] != NULL)
			GpioIrq[PIN_DIO_0]();
	}

	if (i & (1 << PIN_DIO_3))
	{
		if (GpioIrq[PIN_DIO_3] != NULL)
			GpioIrq[PIN_DIO_3]();
	}

	if (i & (1 << PIN_BUTTON_1))
	{
		if (GpioIrq[PIN_BUTTON_1] != NULL)
			GpioIrq[PIN_BUTTON_1]();
	}

	if (i & (1 << PIN_LIGHT_SENSE))
	{
		if (GpioIrq[PIN_LIGHT_SENSE] != NULL)
			GpioIrq[PIN_LIGHT_SENSE]();
	}
}

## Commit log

2017-07-14 Remapped GPIO interrupts
    GPIO interrupt pins have been remapped based on our own hardware
    implementation.
2017-07-14 Added push button support
    Added support to use the push buttons. A button press genererates an
    interrupt.
2017-07-14 Added some GPIO stuff to the main app
    LED1 blinks on transmission (very short, but has an impact on the power
    consumption).
    A press on PB0 toggles LED0.
    [main.c]
2017-07-14 Pre-vacation alpha
    Changes:
    OTAA works (only without USE_AES_HW)
    Omitted the use of linked source files (startup_gcc_efm32hg.s &
    system_efm32hg.c)
    Removed DIO5 interrupt
2017-07-14 Hardware design of the wonder gecko breakout board
    Eagle files for the EFM32 (M0 Cortex) Wonder Gecko Breakout board
    developed by DraMCo.
    Version 1 has been made (and heavily bodged).
    Version 2 is under development.
2017-07-17 Updated hardware schematic
    [v2.brd, v2.sch]
2017-07-18 Updated hardware design
    Finished schematic (final checks needed!)
    Included pdf of the schematic
    First version of the board (no silkscreen yet)
    [v2.brd, v2.sch]
2017-07-18 Updated board design
    [v2.brd, v2.sch]
2017-07-19 Final touches to board design, Gerber files
    [v2.brd, v2.sch]
2017-08-23 Added new "LoRa Extension Board" design
    Hopefully this design will fix the issues encountered with the previous one.
    Added EEPROM and an output pin mux on the I2C bus. Remapped lines to the extension header.
    [v3.brd, v3.sch]
2017-08-23 Added component list for the extension board
2017-08-25 Updated component list
    1) Fixed wrong component name for APDS-9200
    2) Added possible suppliers to the partlist
    [v3.brd, v3.sch]
2017-09-05 Update HW design of the extension board
    Rerouted RST, SDA and SCL
    [v3.1.brd, v3.1.sch]
2017-09-05 I2C outputmux submodule
2017-09-19 Integration of I2C
    I2C working.
    I2C output mux (on expansion board) working.
2017-09-19 Added temp. and humid. sensor support
    Added code to read out the wonder gecko's on-board SI7021 sensor.
2017-09-19 First version of application switching
    The main function now calls a specific main for each tutorial-application.
2017-09-21 Added deep sleep app
    Wake up on button press. Send message to the world. Go back to sleep.
2017-09-28 AES hardware bug fix
    Fixed hard fault that occured when using misaligned memory buffers as input to encrypt_aes().
    [aes_app.c, example_app.c, omux-board.c]
2017-09-28 Fixed small error in documentation
    [deep_sleep_app.c]
2017-09-29 Added I2C EEPROM API
    Allows for reading from and writing to the EEPROM memory on the LoRa expansion board. v3.0 and v3.1 of the hardware need rewiring in order to work with the EEPROM.
2017-09-29 Minor changes
    * Small changes in EEPROM implementation.
    * Replaced "Wonder Gecko" with "Happy Gecko"
    [board.h, eeprom-board.c]
2017-10-03 added error so people change the payload before running the app
    [deep_sleep_app.c]
2017-10-04 Added selection 433/868/915 to pcb (v3.2)
    [v3.2.brd, v3.2.sch]
2017-10-04 Updated power consumption measurements
2017-10-04 removed error from comments
    [deep_sleep_app.c]
2017-10-25 do not use device address en network app session key if OTAA
2017-10-29 Small fix
    OTAA/APB key conflict in aes_app.c
    [aes_app.c]
2018-03-01 New hardware design
    Added v4.0 hardware
    Removed older hardware versions
    v4.0 and v3.2 are the only two versions in use.
    [v2.brd, v2.sch, v3.1.brd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]
